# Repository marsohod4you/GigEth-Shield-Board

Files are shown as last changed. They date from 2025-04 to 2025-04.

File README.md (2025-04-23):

# GigEth-Shield-Board
1G Ethernet Extension PCB for Marsohod3 / Marsohod2 / Marsohod3GW2 boards

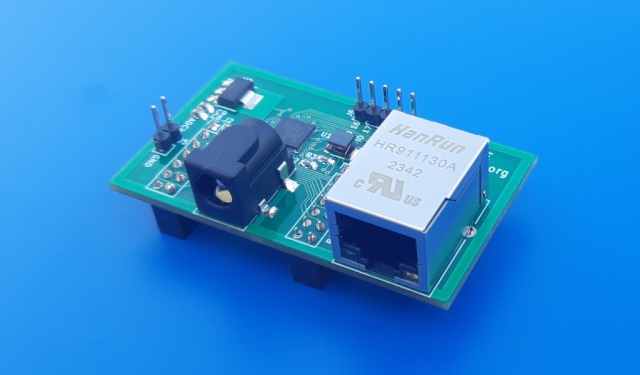
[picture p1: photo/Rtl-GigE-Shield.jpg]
GigEth Shield photo


PCB Board is based on Realtek RTL8211E PHY and released in KiCAD6.
Board can be installed on top of FPGA boards: 
 - Marsohod2
 - Marsohod2bis
 - Marsohod3
 - Marsohod3bis
 - Marsohod3GW2

Ext Board setup example:

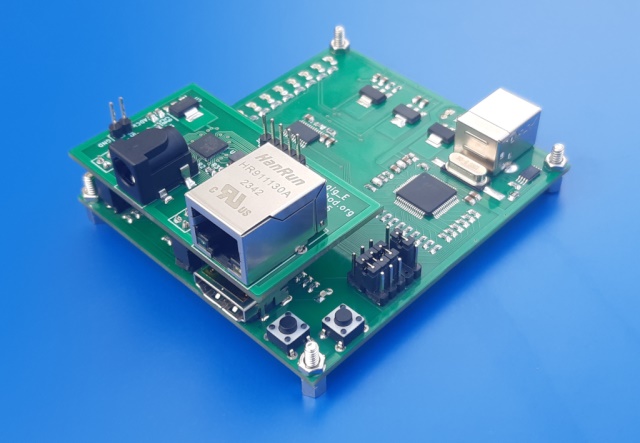
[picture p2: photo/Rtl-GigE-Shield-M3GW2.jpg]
GigEth Shield photo


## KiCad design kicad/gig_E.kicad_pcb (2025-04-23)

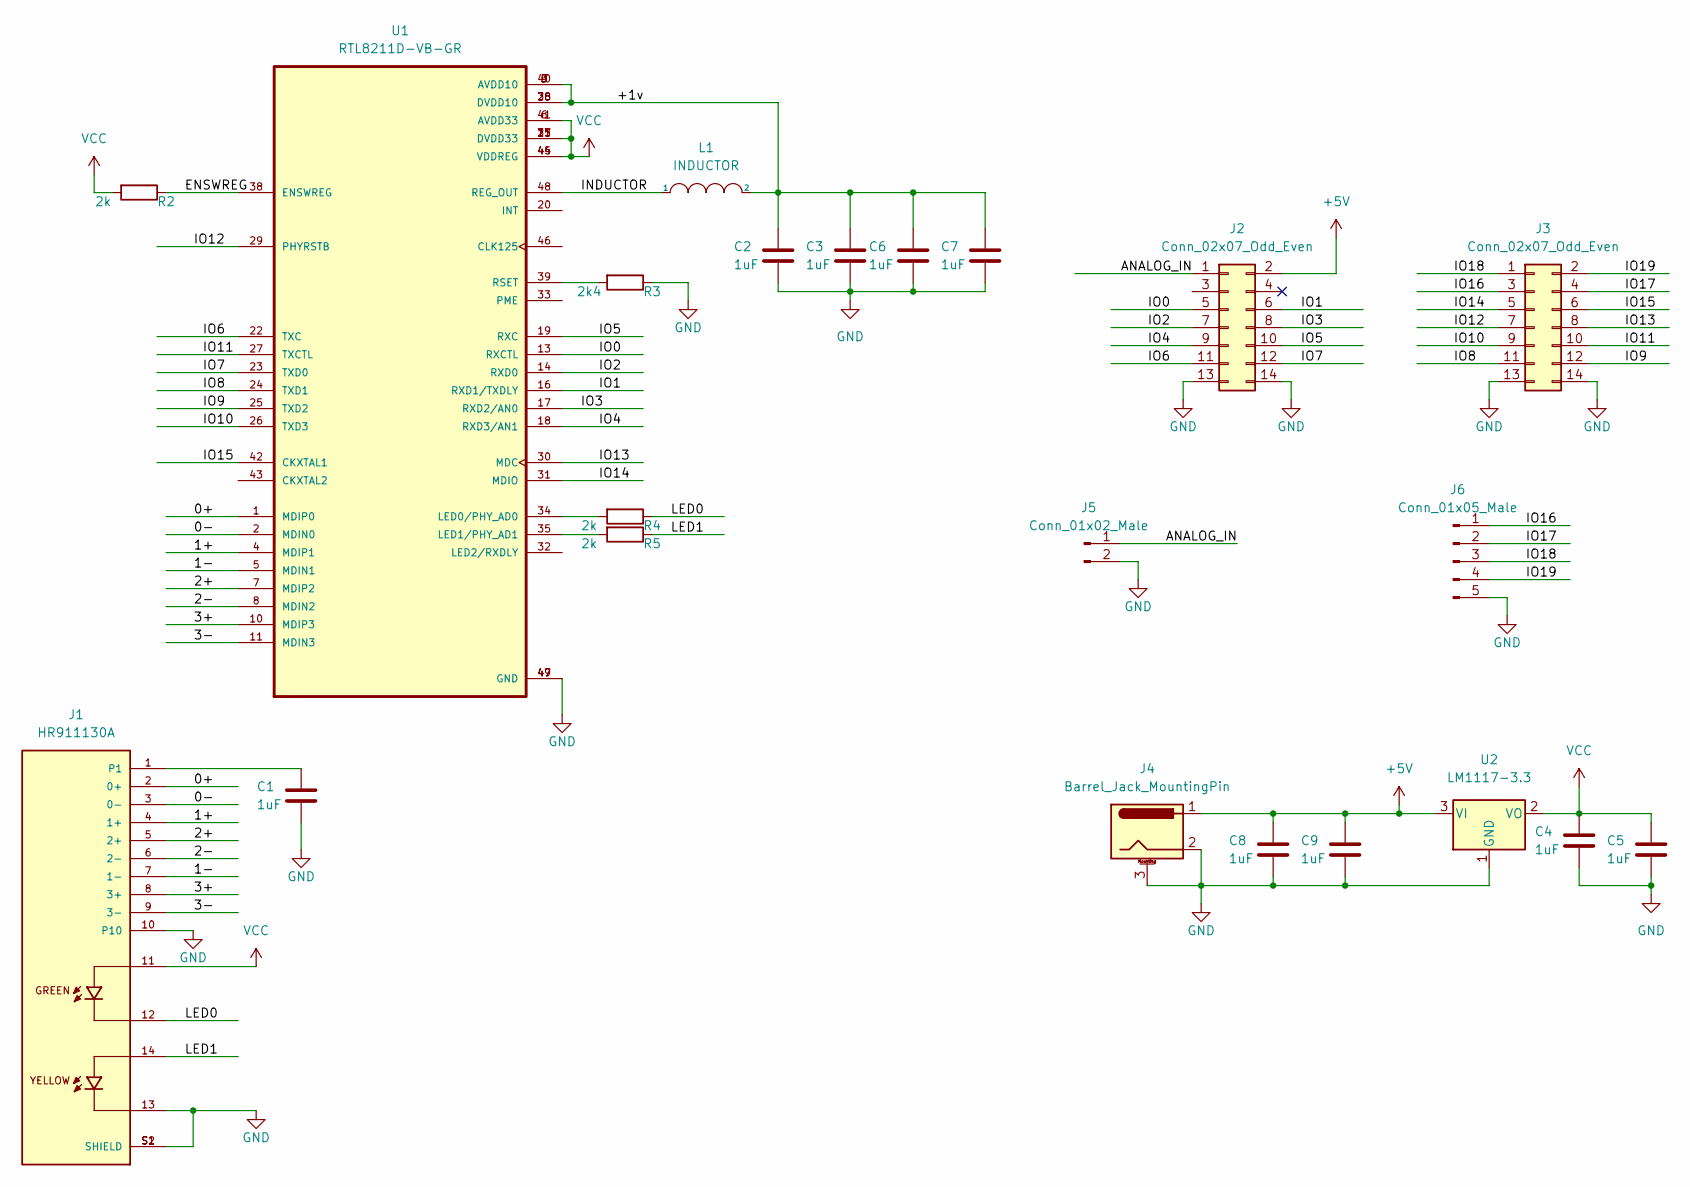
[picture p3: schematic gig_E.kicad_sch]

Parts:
C1, C2, C3, C4, C5, C6, C7, C8, C9: 1uF; C_0805_2012Metric_Pad1.18x1.45mm_HandSolder
J1: HR911130A; HANRUN_HR911130A; PARTREV A
J2, J3: Conn_02x07_Odd_Even; PinHeader_2x07_P2.54mm_Vertical
J4: Barrel_Jack_MountingPin; BarrelJack_CLIFF_FC681465S_SMT_Horizontal
J5: Conn_01x02_Male; PinHeader_1x02_P2.54mm_Vertical
J6: Conn_01x05_Male; PinHeader_1x05_P2.54mm_Vertical
L1: INDUCTOR; L_1812_4532Metric
R2, R4, R5: 2k; R_0805_2012Metric_Pad1.20x1.40mm_HandSolder
R3: 2k4; R_0805_2012Metric_Pad1.20x1.40mm_HandSolder
U1: RTL8211D-VB-GR; QFN-48-1EP_6x6mm_P0.4mm_EP4.3x4.3mm; PARTREV 1.2
U2: LM1117-3.3; SOT-223

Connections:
+5V: C8.1, C9.1, J2.2, J4.1, U2.3 (VI)
/0+: J1.2 (0+), U1.1 (MDIP0)
/0-: J1.3 (0-), U1.2 (MDIN0)
/1+: J1.4 (1+), U1.4 (MDIP1)
/1-: J1.7 (1-), U1.5 (MDIN1)
/2+: J1.5 (2+), U1.7 (MDIP2)
/2-: J1.6 (2-), U1.8 (MDIN2)
/3+: J1.8 (3+), U1.10 (MDIP3)
/3-: J1.9 (3-), U1.11 (MDIN3)
/+1v: C2.1, C3.1, C6.1, C7.1, L1.2, U1.3 (AVDD10), U1.9 (AVDD10), U1.28 (DVDD10), U1.36 (DVDD10), U1.40 (AVDD10)
/ANALOG_IN: J2.1, J5.1
/ENSWREG: R2.1, U1.38 (ENSWREG)
/INDUCTOR: L1.1, U1.48 (REG_OUT)
/IO0: J2.5, U1.13 (RXCTL)
/IO1: J2.6, U1.16 (RXD1/TXDLY)
/IO2: J2.7, U1.14 (RXD0)
/IO3: J2.8, U1.17 (RXD2/AN0)
/IO4: J2.9, U1.18 (RXD3/AN1)
/IO5: J2.10, U1.19 (RXC)
/IO6: J2.11, U1.22 (TXC)
/IO7: J2.12, U1.23 (TXD0)
/IO8: J3.11, U1.24 (TXD1)
/IO9: J3.12, U1.25 (TXD2)
/IO10: J3.9, U1.26 (TXD3)
/IO11: J3.10, U1.27 (TXCTL)
/IO12: J3.7, U1.29 (PHYRSTB)
/IO13: J3.8, U1.30 (MDC)
/IO14: J3.5, U1.31 (MDIO)
/IO15: J3.6, U1.42 (CKXTAL1)
/IO16: J3.3, J6.1
/IO17: J3.4, J6.2
/IO18: J3.1, J6.3
/IO19: J3.2, J6.4
/LED0: J1.12, R4.1
/LED1: J1.14, R5.1
GND: C1.2, C2.2, C3.2, C4.2, C5.2, C6.2, C7.2, C8.2, C9.2, J1.10, J1.13, J1.S1 (SHIELD), J1.S2 (SHIELD), J2.13, J2.14, J3.13, J3.14, J4.2, J4.3 (MountPin), J5.2, J6.5, R3.1, U1.47 (GND), U1.49 (GND), U2.1 (GND)
unnamed: C1.1, J1.1
unnamed: R3.2, U1.39 (RSET)
unnamed: R4.2, U1.34 (LED0/PHY_AD0)
unnamed: R5.2, U1.35 (LED1/PHY_AD1)
VCC: C4.1, C5.1, J1.11, R2.2, U1.6 (AVDD33), U1.15 (DVDD33), U1.21 (DVDD33), U1.37 (DVDD33), U1.41 (AVDD33), U1.44 (VDDREG), U1.45 (VDDREG), U2.2 (VO)

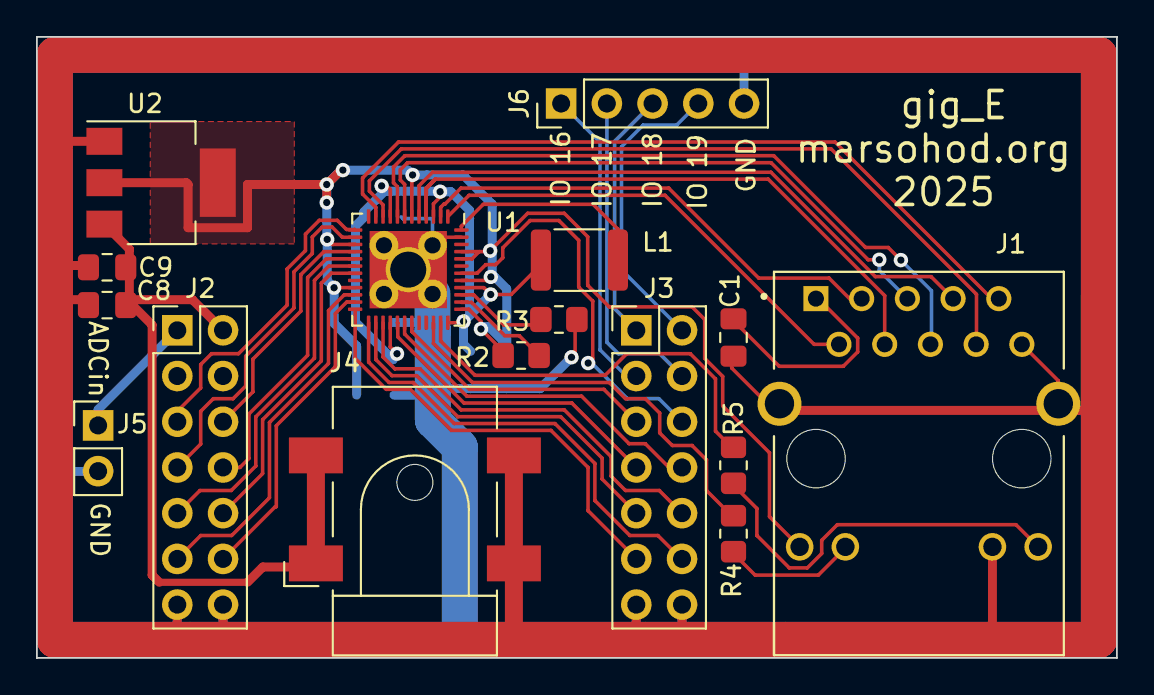
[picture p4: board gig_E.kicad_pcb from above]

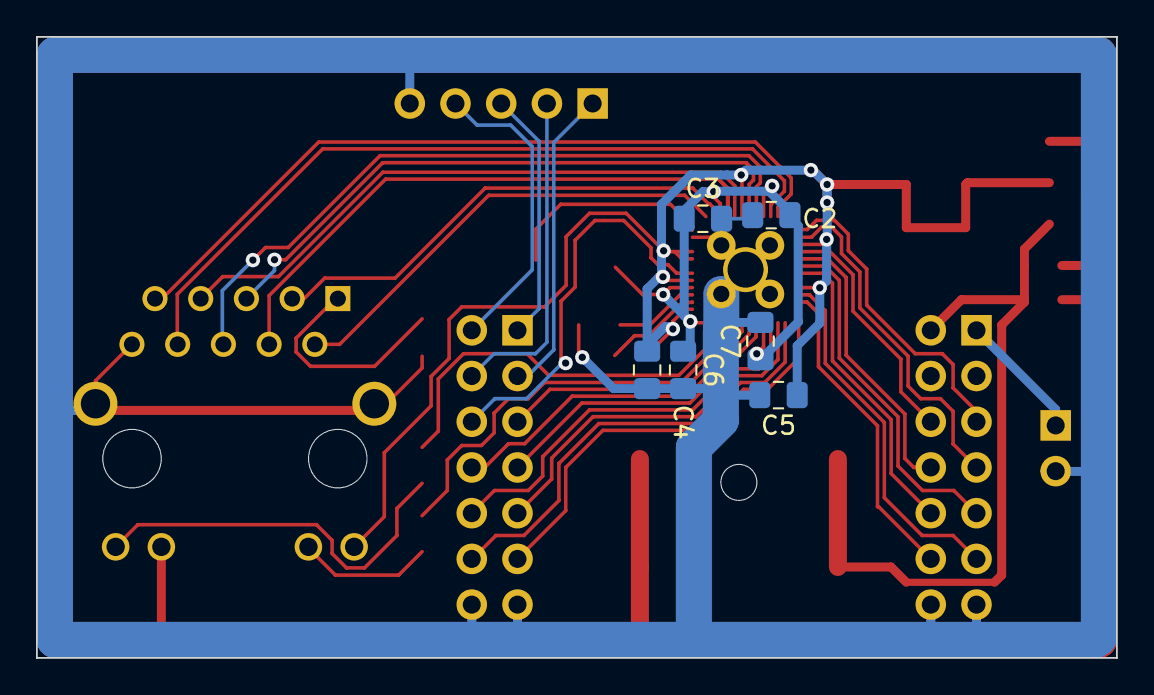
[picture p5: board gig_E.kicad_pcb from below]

Board: 2 copper layers, 60.0 x 34.5 mm, 22 parts (6 on the bottom side), 41 nets.
